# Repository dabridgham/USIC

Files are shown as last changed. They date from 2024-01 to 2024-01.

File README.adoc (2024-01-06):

= USIC - Unibus Storage and I/O Card

The USIC is a Unibus card with an FPGA and SD cards that emulates the old DEC disk
controllers and drives.

This repository is the KiCad project for the hardware, the USIC board
itself.  In addition there are separate projects for a QBUS version of
the board, the http://github.com/dabridgham/QSIC[QSIC], the
http://github.com/dabridgham/QSIC-Verilog[Verilog code] that runs on
the FPGAs, and the code that runs on the embedded soft processor (not
yet started).

A companion http://github.com/dabridgham/Indicator-Panel[indicator
panel] is also available for those who want the blinkenlights.

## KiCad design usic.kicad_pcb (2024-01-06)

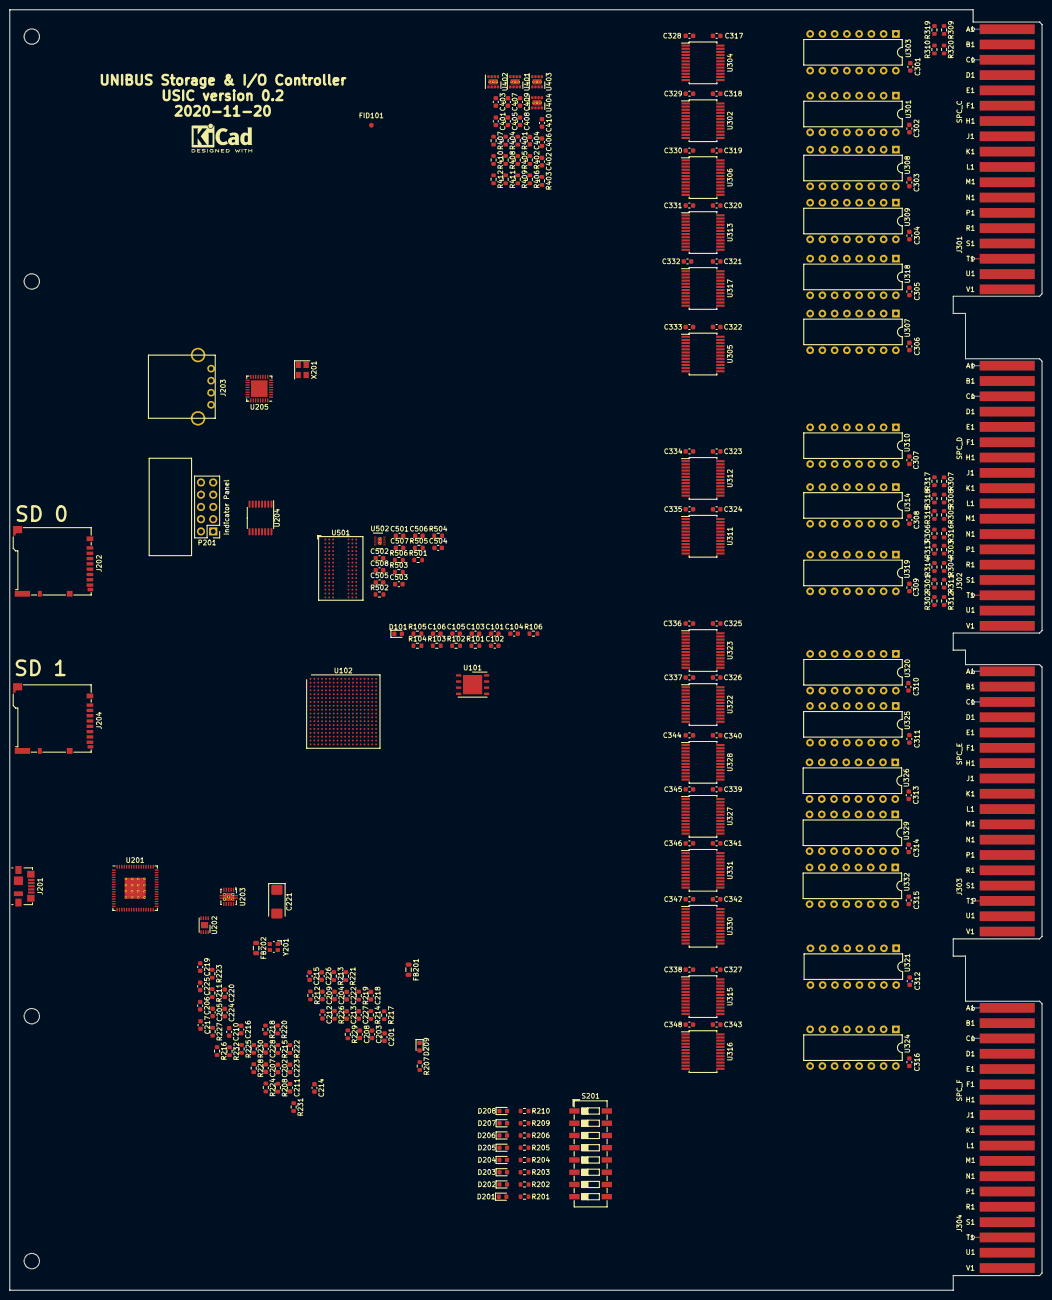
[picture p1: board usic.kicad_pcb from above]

Board: 6 copper layers, 214.1 x 265.6 mm, 253 parts (0 on the bottom side), 359 nets.

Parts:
C101, C102, C103, C104, C106, C218, C226, C401, C405, C407, C409, C501, C502: 22µF 10V; C_0603_1608Metric
C105, C201, C202, C203, C204, C205, C206, C207, C209, C211, C212, C214, C217, C219, C220, C222, C223, C227, C301, C302, C303, C304, C305, C306, C307, C308, C309, C310, C311, C312, C313, C314, C315, C316, C317, C318, C319, C320, C321, C322, C323, C324, C325, C326, C327, C328, C329, C330, C331, C332, C333, C334, C335, C336, C337, C338, C339, C340, C341, C342, C343, C344, C345, C346, C347, C348, C508: 100nF; C_0603_1608Metric
C208, C210: 4.7µF 6.3V; C_0603_1608Metric
C213: 3.3µF 6.3V; C_0603_1608Metric
C215, C216: 8pF; C_0603_1608Metric
C221: 150µF; CP_EIA-6032-28_Kemet-C
C224, C225: 1µF; C_0603_1608Metric
C228: 10nF; C_0603_1608Metric
C402, C403, C404, C406, C408, C410, C503, C504, C505, C506: 10µF 10V; C_0603_1608Metric
C507: 220nF; C_0603_1608Metric
D101, D201, D202, D203, D204, D205, D206, D207, D208, D209: green; LED_0603_1608Metric
FB201, FB202: Ferrite_Bead_Small; L_0805_2012Metric
FID101: Fiducial; Fiducial_1mm_Mask2mm
Handle_101, Handle_102: Handle; DEC-Handle
Handle_Hole_101, Handle_Hole_102, Handle_Hole_103, Handle_Hole_104: MountingHole; mounting hole .125
J201: USB_B_Micro; USB_Micro-B_Molex_47346-0001
J202: SD 0; microSD_HC_Hirose_DM3BT-DSF-PEJS
J203: USB_A; USB-A-Amphenol-UE27
J204: SD 1; microSD_HC_Hirose_DM3BT-DSF-PEJS
J301: SPC_C; DEC_Edge_Fingers_single_height
J302: SPC_D; DEC_Edge_Fingers_single_height
J303: SPC_E; DEC_Edge_Fingers_single_height
J304: SPC_F; DEC_Edge_Fingers_single_height
LOGO101: KiCad Logo; KiCad-Logo2_5mm_SilkScreen
P201: Indicator Panel; Box_Header_2x05_P2.54mm
R101, R102, R105, R106: 4.7k; R_0603_1608Metric
R103: 2.4k; R_0603_1608Metric
R104, R201, R202, R203, R204, R205, R206, R209, R210, R214, R501: 240; R_0603_1608Metric
R207: 1k; R_0603_1608Metric
R208: 12k 1%; R_0603_1608Metric
R211, R212, R213, R504, R505, R506: 10k; R_0603_1608Metric
R215: 2.2k; R_0603_1608Metric
R216, R217: 100k; R_0603_1608Metric
R218, R226: 4.7; R_0603_1608Metric
R219, R220, R221, R222, R223, R227, R228, R229, R230, R231: 50k; R_0603_1608Metric
R224: 56.2k; R_0603_1608Metric
R225: 20k; R_0603_1608Metric
R232: 8.06k; R_0603_1608Metric
R301, R302, R303, R304, R305, R306, R307, R308, R309, R310: 330; R_0603_1608Metric
R311, R312, R313, R314, R315, R316, R317, R318, R319, R320: 680; R_0603_1608Metric
R401: 499k; R_0603_1608Metric
R402: 511k; R_0603_1608Metric
R403: 162k; R_0603_1608Metric
R404, R407, R410: 499k 1%; R_0603_1608Metric
R405: 200k 1%; R_0603_1608Metric
R406, R409, R412: 162k 1%; R_0603_1608Metric
R408: 143k 1%; R_0603_1608Metric
R411: 40.2 1%; R_0603_1608Metric
R502: 89 1%; R_0603_1608Metric
R503: 47k; R_0603_1608Metric
S201: Config; SW_DIP_SPSTx08_Slide_6.7x21.88mm_W6.73mm_P2.54mm_LowProfile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
U101: MT25Q-so8; DFN-8-1EP_6x5mm_P1.27mm_EP4x4mm
U102: XC7A75T-CSG324; Xilinx_CSG324
U201: FT2232HQ; QFN-64-1EP_9x9mm_P0.5mm_EP4.35x4.35mm_ThermalVias
U202: 93CxxC; DFN-8-1EP_3x2mm_P0.5mm_EP1.3x1.5mm
U203: TPS2561; VSON-10-1EP_3x3mm_P0.5mm_EP1.65x2.4mm_ThermalVias
U204: MAX3033E; TSSOP-16_4.4x5mm_P0.65mm
U205: USB3340; QFN-32-1EP_5x5mm_P0.5mm_EP3.45x3.45mm
U301, U303, U307, U308, U309, U310, U314, U318, U319, U320, U321, U324, U325, U326, U329, U332: DS8641-LR; DIP-16_W7.62mm
U302, U304, U305, U306, U311, U312, U313, U315, U316, U317, U322, U323, U327, U328, U330, U331: 74LVC7T245; SSOP-24_5.3x8.2mm_P0.65mm
U401, U402, U403, U404: TPS82085; Texas_SIL0008D_MicroSiP-8-1EP_2.8x3mm_P0.65mm_EP1.1x1.9mm_T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
U501: IS43TR16128B; BGA-96_9.0x13.0mm_Layout2x3x16_P0.8mm
U502: TPS51206; WSON-10-1EP_2x2mm_P0.4mm_EP0.9x1.5mm_ThermalVias
X201: ASE-24.000MHz; Oscillator_SMD_Abracon_ASE-4Pin_3.2x2.5mm
Y201: 12 MHz; Crystal_SMD_Abracon_ABM10-4Pin_2.5x2.0mm

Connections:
/1V0: C404.1, C409.1, R410.1, R411.1, U102.F8 (VCCINT), U102.F10 (VCCBRAM), U102.G7 (VCCINT), U102.G9 (VCCINT), U102.G11 (VCCBRAM), U102.H8 (VCCINT), U102.J7 (VCCINT), U102.J11 (VCCINT), U102.K8 (VCCINT), U102.L7 (VCCINT), U102.L11 (VCCINT), U102.M8 (VCCINT), U102.M10 (VCCINT), U102.N7 (VCCINT), U102.N9 (VCCINT), U102.N11 (VCCINT), U404.8 (Vout)
/1V5: C407.1, C501.1, C502.1, C503.1, C504.1, R407.1, R408.1, U102.A7 (VCCO_35), U102.C3 (VCCO_35), U102.D6 (VCCO_35), U102.F2 (VCCO_35), U102.G5 (VCCO_35), U102.J1 (VCCO_35), U403.8 (Vout), U501.A1 (VDDQ1), U501.A8 (VDDQ2), U501.B2 (VDD1), U501.C1 (VDDQ3), U501.C9 (VDDQ4), U501.D2 (VDDQ5), U501.D9 (VDD2), U501.E9 (VDDQ6), U501.F1 (VDDQ7), U501.G7 (VDD3), U501.H2 (VDDQ8), U501.H9 (VDDQ9), U501.K2 (VDD4), U501.K8 (VDD5), U501.N1 (VDD6), U501.N9 (VDD7), U501.R1 (VDD8), U501.R9 (VDD9), U502.1 (VDDQSNS)
/1V8: C403.1, C405.1, R404.1, R405.1, U102.F12 (VCCAUX), U102.H10 (VCCADC_0), U102.H12 (VCCAUX), U102.K12 (VCCAUX), U102.M12 (VCCAUX), U402.8 (Vout)
/3V3: C101.1, C102.2, C103.1, C104.2, C105.2, C106.2, C203.1, C205.1, C206.1, C211.1, C212.1, C214.2, C220.2, C222.1, C223.1, C228.1, C328.1, C329.1, C330.1, C331.1, C332.1, C333.1, C334.1, C335.1, C336.1, C337.1, C338.1, C344.1, C345.1, C346.1, C347.1, C348.1, C401.1, C505.1, C508.1, D209.2 (A), FB201.2, FB202.2, R101.1, R102.1, R103.1, R104.1, R105.1, R106.1, R201.1, R202.1, R203.1, R204.1, R205.1, R206.1, R207.2, R209.1, R210.1, R211.1, R212.1, R213.1, R218.2, R219.1, R220.1, R221.1, R222.1, R223.1, R226.2, R227.1, R228.1, R229.1, R230.1, R231.1, R401.1, R402.1, R505.2, R506.2, U101.8 (Vcc), U102.A17 (VCCO_15), U102.B10 (VCCO_16), U102.C13 (VCCO_15), U102.D16 (VCCO_15), U102.G15 (VCCO_15), U102.H18 (VCCO_15), U102.K4 (VCCO_34), U102.K14 (VCCO_15), U102.L17 (VCCO_14), U102.N3 (VCCO_34), U102.N13 (VCCO_14), U102.P6 (VCCO_34), U102.P8 (CFGBVS_0), U102.P12 (M0_0), U102.P16 (VCCO_14), U102.T2 (VCCO_34), U102.T12 (VCCO_14), U102.U5 (VCCO_34), U102.U15 (VCCO_14), U102.V8 (VCCO_34), U102.V18 (VCCO_14), U201.20 (VCCIO), U201.31 (VCCIO), U201.42 (VCCIO), U201.50 (VREGIN), U201.56 (VCCIO), U202.6 (ORG), U202.8 (VCC), U204.4 (EN12), U204.12 (EN34), U204.16 (VDD), U205.8 (REFSEL[0]), U205.11 (REFSEL[1]), U205.14 (REFSEL[2]), U205.21 (VBAT), U205.32 (VDDIO), U302.1 (VCCa), U302.2 (A->B), U304.1 (VCCa), U304.2 (A->B), U305.1 (VCCa), U306.1 (VCCa), U311.1 (VCCa), U311.2 (A->B), U312.1 (VCCa), U313.1 (VCCa), U313.2 (A->B), U315.1 (VCCa), U315.2 (A->B), U316.1 (VCCa), U317.1 (VCCa), U322.1 (VCCa), U322.2 (A->B), U323.1 (VCCa), U327.1 (VCCa), U327.2 (A->B), U328.1 (VCCa), U330.1 (VCCa), U330.2 (A->B), U331.1 (VCCa), U401.8 (Vout), U502.2 (VLDOIN), U502.10 (VDD), X201.4 (Vdd)
/5V0: C217.1, C301.1, C302.1, C303.1, C304.1, C305.1, C306.1, C307.1, C308.1, C309.1, C310.1, C311.1, C312.1, C313.1, C314.1, C315.1, C316.1, C317.1, C318.1, C319.1, C320.1, C321.1, C322.1, C323.1, C324.1, C325.1, C326.1, C327.1, C339.1, C340.1, C341.1, C342.1, C343.1, C402.1, C406.1, C408.1, C410.1, J301.A2 (+5V), J302.A2 (+5V), J303.A2 (+5V), J304.A2 (+5V), R216.1, R217.1, R301.1, R302.1, R303.1, R304.1, R305.1, R306.1, R307.1, R308.1, R309.1, R310.1, U203.2 (IN), U203.3 (IN), U301.16 (VCC), U302.23 (VCCb), U302.24 (VCCb), U303.16 (VCC), U304.23 (VCCb), U304.24 (VCCb), U305.23 (VCCb), U305.24 (VCCb), U306.23 (VCCb), U306.24 (VCCb), U307.16 (VCC), U308.16 (VCC), U309.16 (VCC), U310.16 (VCC), U311.23 (VCCb), U311.24 (VCCb), U312.23 (VCCb), U312.24 (VCCb), U313.23 (VCCb), U313.24 (VCCb), U314.16 (VCC), U315.23 (VCCb), U315.24 (VCCb), U316.23 (VCCb), U316.24 (VCCb), U317.23 (VCCb), U317.24 (VCCb), U318.16 (VCC), U319.16 (VCC), U320.16 (VCC), U321.16 (VCC), U322.23 (VCCb), U322.24 (VCCb), U323.23 (VCCb), U323.24 (VCCb), U324.16 (VCC), U325.16 (VCC), U326.16 (VCC), U327.23 (VCCb), U327.24 (VCCb), U328.23 (VCCb), U328.24 (VCCb), U329.16 (VCC), U330.23 (VCCb), U330.24 (VCCb), U331.23 (VCCb), U331.24 (VCCb), U332.16 (VCC), U401.1 (En), U401.3 (Vin), U401.4 (Vin), U402.1 (En), U402.3 (Vin), U402.4 (Vin), U403.1 (En), U403.3 (Vin), U403.4 (Vin), U404.1 (En), U404.3 (Vin), U404.4 (Vin)
/CLK_INPUT: U102.D15 (IO_L12P_T1_MRCC_15), U102.H16 (IO_L13P_T2_MRCC_15), U102.N5 (IO_L13P_T2_MRCC_34), U102.P15 (IO_L13P_T2_MRCC_14), U102.P17 (IO_L12P_T1_MRCC_14), U102.T5 (IO_L12P_T1_MRCC_34)
/I/O/D+: J201.3 (D+), U201.8 (D+)
/I/O/D-: J201.2 (D-), U201.7 (D-)
/I/O/IPblank_N: P201.7, U204.5 (O2-)
/I/O/IPblank_P: P201.6, U204.6 (O2+)
/I/O/IPclk_N: P201.10, U204.3 (O1-)
/I/O/IPclk_P: P201.9, U204.2 (O1+)
/I/O/IPdata_N: P201.2, U204.13 (O4-)
/I/O/IPdata_P: P201.1, U204.14 (O4+)
/I/O/IPlatch_N: P201.5, U204.11 (O3-)
/I/O/IPlatch_P: P201.4, U204.10 (O3+)
/LED_0: D201.1 (K), U102.V9 (IO_L21N_T3_DQS_34)
/LED_1: D202.1 (K), U102.U7 (IO_L22P_T3_34)
/LED_2: D203.1 (K), U102.U6 (IO_L22N_T3_34)
/LED_3: D204.1 (K), U102.R7 (IO_L23P_T3_34)
/LED_4: D205.1 (K), U102.T6 (IO_L23N_T3_34)
/LED_5: D206.1 (K), U102.R8 (IO_L24P_T3_34)
/LED_6: D207.1 (K), U102.T8 (IO_L24N_T3_34)
/LED_7: D208.1 (K), U102.U8 (IO_25_34)
/Memory/A0: U102.C5 (IO_L1N_T0_AD4N_35), U501.N3 (A0)
/Memory/A1: U102.B6 (IO_L2N_T0_AD12N_35), U501.P7 (A1)
/Memory/A2: U102.C7 (IO_L4N_T0_35), U501.P3 (A2)
/Memory/A3: U102.D5 (IO_L11P_T1_SRCC_35), U501.N2 (A3)
/Memory/A4: U102.A3 (IO_L8N_T1_AD14N_35), U501.P8 (A4)
/Memory/A5: U102.E7 (IO_L6P_T0_35), U501.P2 (A5)
/Memory/A6: U102.A4 (IO_L8P_T1_AD14P_35), U501.R8 (A6)
/Memory/A7: U102.C6 (IO_L1P_T0_AD4P_35), U501.R2 (A7)
/Memory/A8: U102.A6 (IO_L3P_T0_DQS_AD5P_35), U501.T8 (A8)
/Memory/A9: U102.D8 (IO_L4P_T0_35), U501.R3 (A9)
/Memory/A10: U102.B2 (IO_L10N_T1_AD15N_35), U501.L7 (A10/AP)
/Memory/A11: U102.A5 (IO_L3N_T0_DQS_AD5N_35), U501.R7 (A11)
/Memory/A12: U102.B3 (IO_L10P_T1_AD15P_35), U501.N7 (A12/BC#)
/Memory/A13: U102.B7 (IO_L2P_T0_AD12P_35), U501.T3 (A13)
/Memory/BA0: U102.E5 (IO_L5N_T0_AD13N_35), U501.M2 (BA0)
/Memory/BA1: U102.A1 (IO_L9N_T1_DQS_AD7N_35), U501.N8 (BA1)
/Memory/BA2: U102.E6 (IO_L5P_T0_AD13P_35), U501.M3 (BA2)
/Memory/CAS#: U102.D3 (IO_L12N_T1_MRCC_35), U501.K3 (CAS#)
/Memory/CK: R502.2, U102.C4 (IO_L7P_T1_AD6P_35), U501.J7 (CK)
/Memory/CK#: R502.1, U102.B4 (IO_L7N_T1_AD6N_35), U501.K7 (CK#)
/Memory/CKE: U102.B1 (IO_L9P_T1_DQS_AD7P_35), U501.K9 (CKE)
/Memory/DML: U102.G1 (IO_L17N_T2_35), U501.E7 (DML)
/Memory/DMU: U102.G6 (IO_L19P_T3_35), U501.D3 (DMU)
/Memory/DQL0: U102.H1 (IO_L17P_T2_35), U501.E3 (DQL0)
/Memory/DQL1: U102.F1 (IO_L18P_T2_35), U501.F7 (DQL1)
/Memory/DQL2: U102.E2 (IO_L14P_T2_SRCC_35), U501.F2 (DQL2)
/Memory/DQL3: U102.E1 (IO_L18N_T2_35), U501.F8 (DQL3)
/Memory/DQL4: U102.F4 (IO_L13P_T2_MRCC_35), U501.H3 (DQL4)
/Memory/DQL5: U102.C1 (IO_L16N_T2_35), U501.H8 (DQL5)
/Memory/DQL6: U102.F3 (IO_L13N_T2_MRCC_35), U501.G2 (DQL6)
/Memory/DQL7: U102.D2 (IO_L14N_T2_SRCC_35), U501.H7 (DQL7)
/Memory/DQSL: U102.H2 (IO_L15P_T2_DQS_35), U501.F3 (DQSL)
/Memory/DQSL#: U102.G2 (IO_L15N_T2_DQS_35), U501.G3 (DQSL#)
/Memory/DQSU: U102.J4 (IO_L21P_T3_DQS_35), U501.C7 (DQSU)
/Memory/DQSU#: U102.H4 (IO_L21N_T3_DQS_35), U501.B7 (DQSU#)
/Memory/DQU0: U102.G4 (IO_L20P_T3_35), U501.D7 (DQU0)
/Memory/DQU1: U102.H5 (IO_L24N_T3_35), U501.C3 (DQU1)
/Memory/DQU2: U102.G3 (IO_L20N_T3_35), U501.C8 (DQU2)
/Memory/DQU3: U102.H6 (IO_L24P_T3_35), U501.C2 (DQU3)
/Memory/DQU4: U102.J2 (IO_L22N_T3_35), U501.A7 (DQU4)
/Memory/DQU5: U102.J3 (IO_L22P_T3_35), U501.A2 (DQU5)
/Memory/DQU6: U102.K1 (IO_L23N_T3_35), U501.B8 (DQU6)
/Memory/DQU7: U102.K2 (IO_L23P_T3_35), U501.A3 (DQU7)
/Memory/ODT: U102.F5 (IO_0_35), U501.K1 (ODT)
/Memory/RAS#: U102.E3 (IO_L12P_T1_MRCC_35), U501.J3 (RAS#)
/Memory/RESET#: R503.1, U102.J5 (IO_25_35), U501.T2 (RESET#)
/Memory/VREF15: C507.1, U102.D7 (IO_L6N_T0_VREF_35), U102.F6 (IO_L19N_T3_VREF_35), U501.H1 (VREFDQ), U501.M8 (VREFCA), U502.6 (VTTREF)
/Memory/WE#: U102.D4 (IO_L11N_T1_SRCC_35), U501.L3 (WE#)
/PROG_B: R106.2, U102.P9 (PROGRAM_B_0)
/RXD: U102.B9 (IO_L11N_T1_SRCC_16), U201.39 (BDBUS1)
/SW_0: S201.8, U102.U1 (IO_L7P_T1_34)
/SW_1: S201.7, U102.V1 (IO_L7N_T1_34)
/SW_2: S201.6, U102.U4 (IO_L8P_T1_34)
/SW_3: S201.5, U102.U3 (IO_L8N_T1_34)
/SW_4: S201.4, U102.U2 (IO_L9P_T1_DQS_34)
/SW_5: S201.3, U102.V2 (IO_L9N_T1_DQS_34)
/SW_6: S201.2, U102.V5 (IO_L10P_T1_34)
/SW_7: S201.1, U102.V4 (IO_L10N_T1_34)
/TCK: U102.E10 (TCK_0), U201.16 (ADBUS0)
/TDI: U102.E11 (TDI_0), U201.17 (ADBUS1)
/TDO: U102.E13 (TDO_0), U201.18 (ADBUS2)
/TMS: U102.E12 (TMS_0), U201.19 (ADBUS3)
/TXD: U102.C9 (IO_L11P_T1_SRCC_16), U201.38 (BDBUS0)
/Unibus/A0: J303.H2 (A00), U325.1 (bus3)
/Unibus/A1: J303.H1 (A01), U325.15 (bus1)
/Unibus/A2: J303.F1 (A02), U325.12 (bus2)
/Unibus/A3: J303.V2 (A03), U332.15 (bus1)
/Unibus/A4: J303.U2 (A04), U332.1 (bus3)
/Unibus/A5: J303.V1 (A05), U332.12 (bus2)
/Unibus/A6: J303.U1 (A06), U332.4 (bus4)
/Unibus/A7: J303.P2 (A07), U329.1 (bus3)
/Unibus/A8: J303.N2 (A08), U329.4 (bus4)
/Unibus/A9: J303.R1 (A09), U329.15 (bus1)
/Unibus/A10: J303.P1 (A10), U329.12 (bus2)
/Unibus/A11: J303.L1 (A11), U326.15 (bus1)
/Unibus/A12: J303.C1 (A12), U320.1 (bus3)
/Unibus/A13: J303.K2 (A13), U326.1 (bus3)
/Unibus/A14: J303.K1 (A14), U326.4 (bus4)
/Unibus/A15: J303.D2 (A15), U320.12 (bus2)
/Unibus/A16: J303.E2 (A16), U320.4 (bus4)
/Unibus/A17: J303.D1 (A17), U320.15 (bus1)
/Unibus/AC_LO: J301.V1 (AC_LO), U305.8 (A5), U307.1 (bus3)
/Unibus/BBSY: J304.D1 (BBSY), U324.1 (bus3)
/Unibus/BG4_in: J302.S2 (BG4_in), R301.2, R311.1, U312.9 (A6), U319.15 (bus1)
/Unibus/BG4_out: J302.T2 (BG4_out), R302.2, R312.1, U311.8 (A5), U319.12 (bus2)
/Unibus/BG5_in: J302.P2 (BG5_in), R303.2, R313.1, U312.10 (A7), U319.4 (bus4)
/Unibus/BG5_out: J302.R2 (BG5_out), R304.2, R314.1, U311.9 (A6), U319.1 (bus3)
/Unibus/BG6_in: J302.M2 (BG6_in), R305.2, R315.1, U312.8 (A5), U314.15 (bus1)
/Unibus/BG6_out: J302.N2 (BG6_out), R306.2, R316.1, U311.6 (A3), U314.12 (bus2)
/Unibus/BG7_in: J302.K2 (BG7_in), R307.2, R317.1, U310.12 (bus2), U312.6 (A3)
/Unibus/BG7_out: J302.L2 (BG7_out), R308.2, R318.1, U311.7 (A4), U314.1 (bus3)
/Unibus/BR4: J302.H2 (BR4), U310.15 (bus1)
/Unibus/BR5: J302.F2 (BR5), U310.1 (bus3)
/Unibus/BR6: J302.E2 (BR6), U310.4 (bus4)
/Unibus/BR7: J302.D2 (BR7), U307.12 (bus2)
/Unibus/C0: J303.J2 (C0), U321.4 (bus4)
/Unibus/C1: J303.F2 (C1), U321.1 (bus3)
/Unibus/D0: J301.S2 (D00), U318.15 (bus1)
/Unibus/D1: J301.R2 (D01), U309.4 (bus4)
/Unibus/D2: J301.U2 (D02), U318.1 (bus3)
/Unibus/D3: J301.T2 (D03), U318.12 (bus2)
/Unibus/D4: J301.N2 (D04), U309.12 (bus2)
/Unibus/D5: J301.P2 (D05), U309.1 (bus3)
/Unibus/D6: J301.V2 (D06), U318.4 (bus4)
/Unibus/D7: J301.M2 (D07), U309.15 (bus1)
/Unibus/D8: J301.L2 (D08), U308.4 (bus4)
/Unibus/D9: J301.K2 (D09), U308.1 (bus3)
/Unibus/D10: J301.J2 (D10), U308.12 (bus2)
/Unibus/D11: J301.H1 (D11), U308.15 (bus1)
/Unibus/D12: J301.H2 (D12), U301.4 (bus4)
/Unibus/D13: J301.F2 (D13), U301.1 (bus3)
/Unibus/D14: J301.E2 (D14), U301.12 (bus2)
/Unibus/D15: J301.D2 (D15), U301.15 (bus1)
/Unibus/DC_LO: J301.N1 (DC_LO), U305.7 (A4), U307.4 (bus4)
/Unibus/INIT: J302.L1 (INIT), U314.4 (bus4)
/Unibus/INTR: J304.M1 (INTR), U324.15 (bus1)
/Unibus/MSYN: J303.E1 (MSYN), U321.15 (bus1)
/Unibus/NPG_in: J301.A1 (NPG_in), R309.2, R319.1, U303.1 (bus3), U305.4 (A1)
/Unibus/NPG_out: J301.B1 (NPG_out), R310.2, R320.1, U303.4 (bus4), U304.3 (A0)
/Unibus/NPR: J304.J1 (NPR), U324.4 (bus4)
/Unibus/PA: J301.C1 (PA), U303.15 (bus1)
/Unibus/PB: J301.S1 (PB), U307.15 (bus1)
/Unibus/SACK: J304.T2 (SACK), U324.12 (bus2)
/Unibus/SSYN: J303.J1 (SSYN), U321.12 (bus2)
/Unibus/~RxA: U323.22 (~OE), U328.22 (~OE), U331.22 (~OE)
/Unibus/~RxD: U306.22 (~OE), U317.22 (~OE)
/Unibus/~TxA_5: U311.14 (B7), U320.7 (disB), U325.7 (disB), U326.7 (disB), U329.7 (disB), U332.7 (disB)
/Unibus/~TxD_5: U301.7 (disB), U304.14 (B7), U308.7 (disB), U309.7 (disB), U318.7 (disB)
/ip_blank: U102.V7 (IO_L20P_T3_34), U204.7 (I2)
/ip_clk: U102.R5 (IO_L19N_T3_VREF_34), U204.1 (I1)
/ip_data: U102.U9 (IO_L21P_T3_DQS_34), U204.15 (I4)
/ip_latch: U102.V6 (IO_L20N_T3_34), U204.9 (I3)
/sd0_clk: J202.5 (CLK), U102.P2 (IO_L15P_T2_DQS_34)
/sd0_cmd: J202.3 (CMD), R221.2, U102.P3 (IO_L14N_T2_SRCC_34)
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
